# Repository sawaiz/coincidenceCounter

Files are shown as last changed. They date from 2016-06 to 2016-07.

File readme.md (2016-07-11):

# Coincidence Counter
The coincidence counter was developed as a means to collect data from cosmic ray detectors in a more cost efficient and straightforward way. The counter must collect, amplify, digitize, and record the coincidence of the analog signals from the detectors. The module attaches to the top of a Raspberry Pi and data is collected from the GPIO pins.

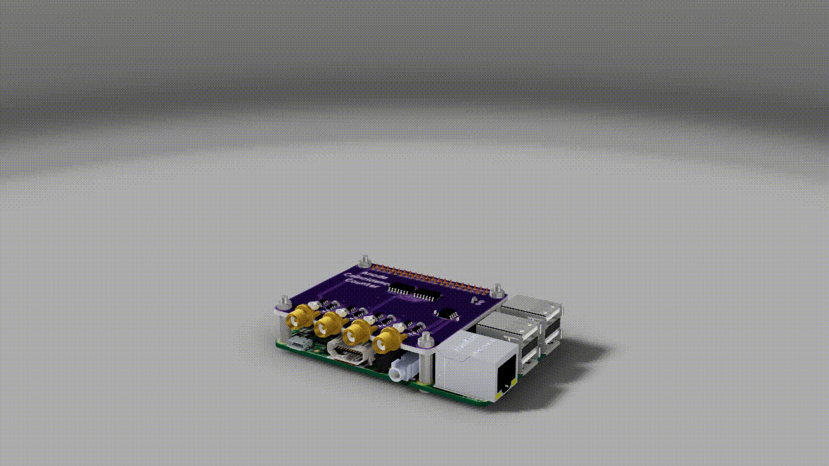
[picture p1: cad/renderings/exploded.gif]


## Electronics
The incoming signal (51 ohm termination) is first amplified by a factor of 10, with a [LT1809CS6](http://cds.linear.com/docs/en/datasheet/180910fa.pdf), a high bandwidth (320Mhz) operational amplifier in a non inverting configuration. This signal is fed into a ultrafast comparator [LT1719CS](http://cds.linear.com/docs/en/datasheet/1719fa.pdf) that has its threshold set through a potentiometer. Nanosecond level (10ns-100ns) signals are able to be digitized and sent out for analysis. The output is then put thorough the six possible *ANDs* of four signals which leads to interrupt pins on the Raspberry Pi.

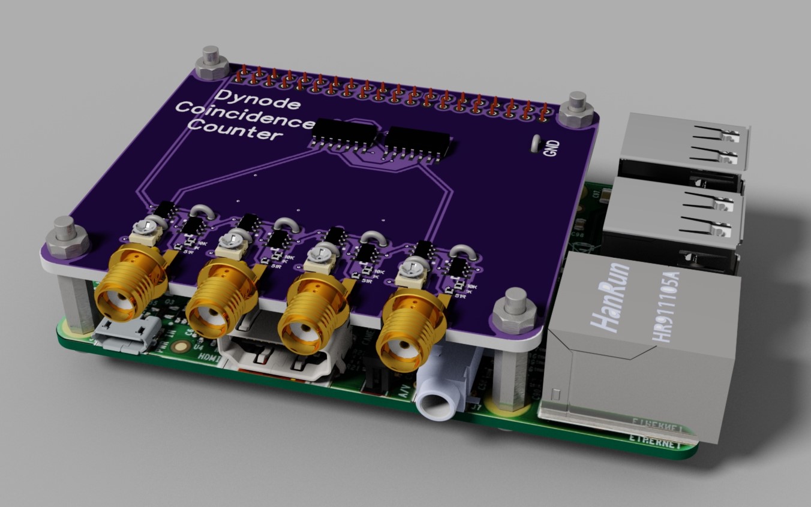
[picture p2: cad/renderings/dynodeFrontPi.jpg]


## Physical
The board is made with the [Pi HAT](https://github.com/raspberrypi/hats) specification, and leaves sufficient room for SMA cables to be attached. It does not contain a self configuration EEPROM. Its outputs are directly connected to the following pins.

| Output | GPIO | Inputs |
| --- | ----:| --- |
| 1 | 22 | CH1 & CH2 |
| 2 | 27 | CH3 & CH1 |
| 3 | 17 | CH1 & CH4 |
| 4 |  5 | CH4 & CH3 |
| 5 |  6 | CH2 & CH3 |
| 6 | 26 | CH2 & CH4 |

The board also has many test points, allowing checking of the signal, and setting of the potentiometers is a easier manner.

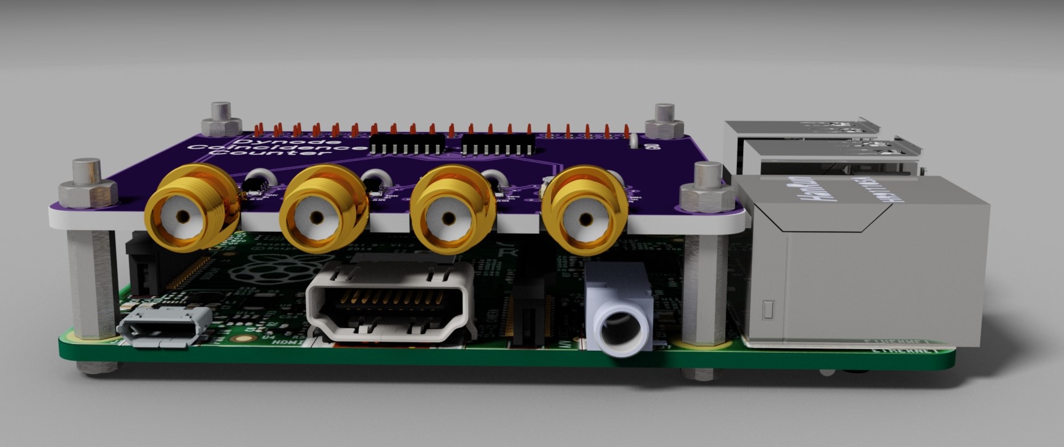
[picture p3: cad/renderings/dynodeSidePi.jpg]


## Usage
The repository [coincidenceControl](nope, deosnt exist yet) has instructions for installing and gathering data from this hardware.

[exploded]: cad/renderings/exploded.gif "Exploded animation of PCB"
[dynodeSidePi]: cad/renderings/dynodeSidePi.jpg "Side view showing clearance from other connectors"
[dynodeFrontPi]: cad/renderings/dynodeFrontPi.jpg "Board showing potentiometers and test points."

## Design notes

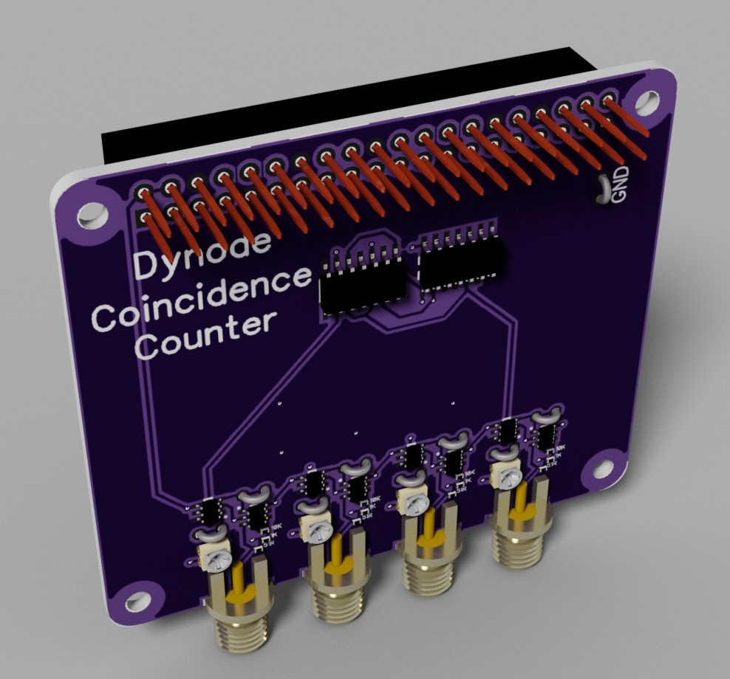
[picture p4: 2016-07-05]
cad/renderings/dinode isometric.jpg

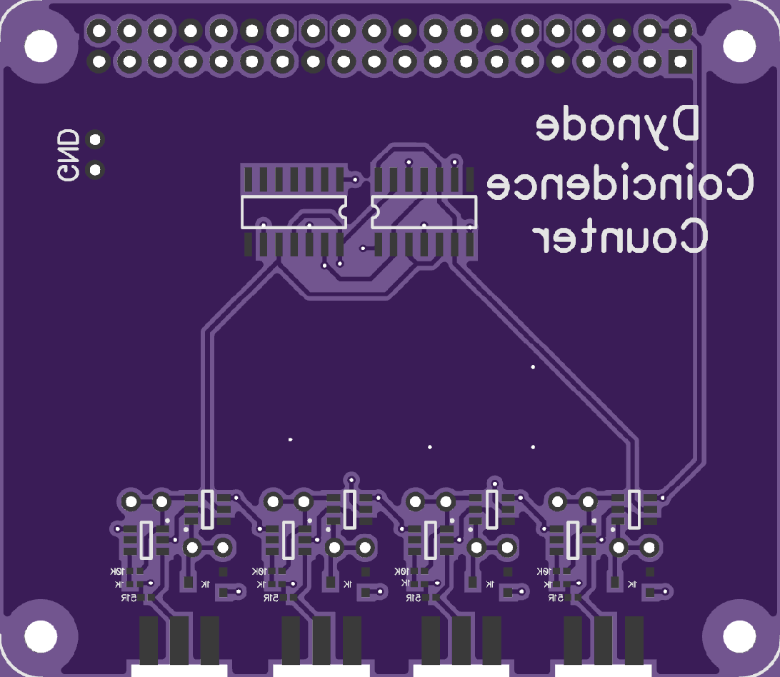
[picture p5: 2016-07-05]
cad/decals/top.png

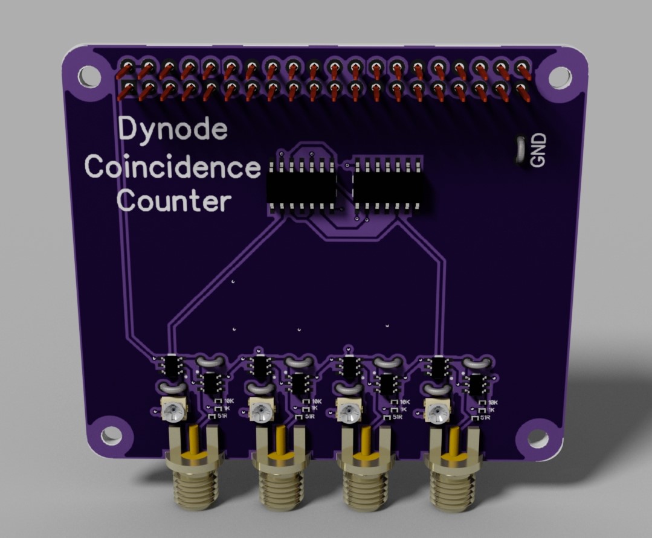
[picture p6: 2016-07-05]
cad/renderings/dinode front.jpg

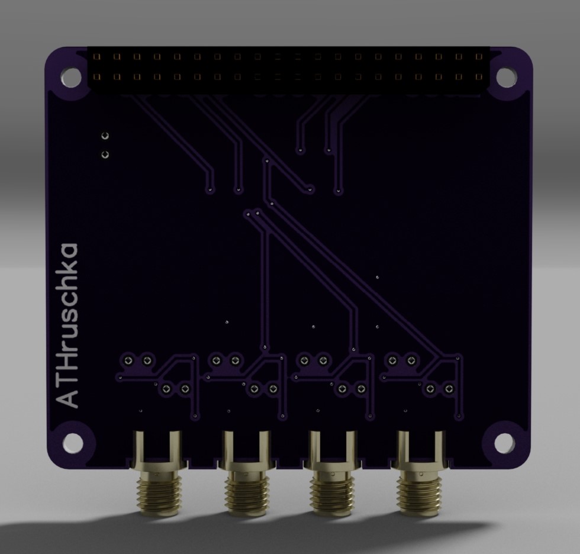
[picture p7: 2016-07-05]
cad/renderings/dinode back.jpg

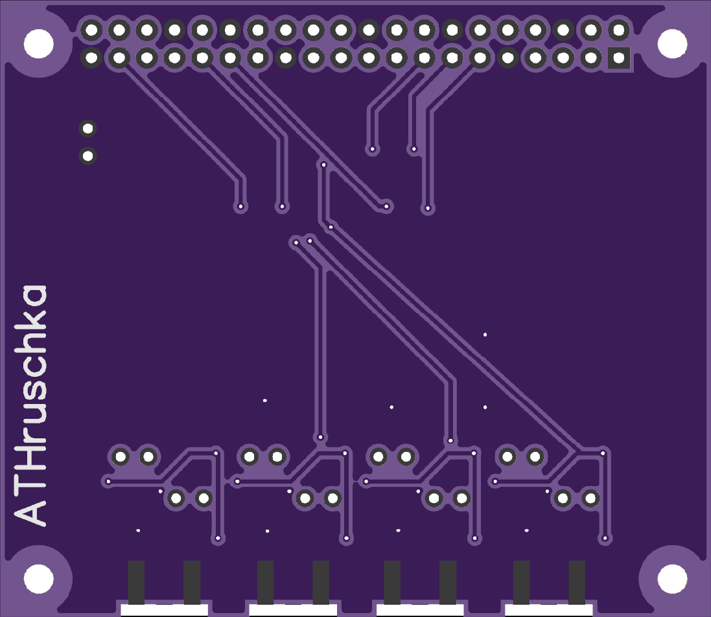
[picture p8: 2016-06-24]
cad/decals/bot.png

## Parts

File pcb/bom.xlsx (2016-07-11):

Ref-Des | Function | Description | P/N | Digikey P/N | QTY | Unit Price | Price Point | Extended Price | URL
R9 | res | RES SMD 1K OHM 5% 1/16W 0402 | CRG0402J1K0 | A106129CT-ND | 4 | $0.0037 | 100 | $0.01 | http://www.digikey.com/product-detail/en/te-connectivity-amp-connectors/CRG0402J1K0/A106129CT-ND/3477786
J1 | Analog Input | CONN SMA JACK 50 OHM EDGE MNT | CONSMA003.062 | CONSMA003.062 | 4 | $3.3700 | 1 | $13.48 | http://www.digikey.com/scripts/DkSearch/dksus.dll?Detail&itemSeq=200735391&uq=636027004667341576
U1 | NAND Gate | IC GATE NAND 4CH 2-INP 14-SO | 74HC00D,653 | 568-1379-1-ND | 2 | $0.4400 | 1 | $0.88 | http://www.digikey.com/scripts/DkSearch/dksus.dll?Detail&itemSeq=200735074&uq=636027004667321576
U2 | Analog to Digital Signal | IC COMP R-RINOUT SINGLE SOT23-6 | LT1719CS6#TRMPBF | LT1719CS6#TRMPBFCT-ND | 4 | $4.4800 | 1 | $17.92 | http://www.digikey.com/scripts/DkSearch/dksus.dll?Detail&itemSeq=200735921&uq=636027008193055389
U3 | Inverting Amplification of Signal | IC OPAMP GP 180MHZ RRO TSOT23-6 | LT1809CS6#TRMPBF | LT1809CS6#TRMPBFCT-ND | 4 | $4.4700 | 10 | $17.88 | http://www.digikey.com/product-detail/en/linear-technology/LT1809CS6-TRMPBF/LT1809CS6-TRMPBFCT-ND/891475
R8 | Potentiometer | TRIMMER 1K OHM 0.1W SMD | PVZ3A102C01R00 | 490-7004-1-ND | 4 | $0.1640 | 10 | $0.66 | http://www.digikey.com/scripts/DkSearch/dksus.dll?Detail&itemSeq=200735381&uq=636027011087621576
R10 | Res | RES SMD 51 OHM 0.5% 1/16W 0402 | RT0402DRE0751RL | 311-51UCT-ND | 4 | $0.0275 | 100 | $0.11 | http://www.digikey.com/product-detail/en/yageo/RT0402DRE0751RL/311-51UCT-ND/1037159
R | Res | RES SMD 10K OHM 0.1% 1/16W 0402 | RNCF0402BTE10K0 | RNCF0402BTE10K0CT-ND | 4 | $0.3100 | 10 | $1.24 | http://www.digikey.com/scripts/DkSearch/dksus.dll?Detail&itemSeq=200737314&uq=636027016498025803
 |  |  |  |  |  |  |  | $52.18

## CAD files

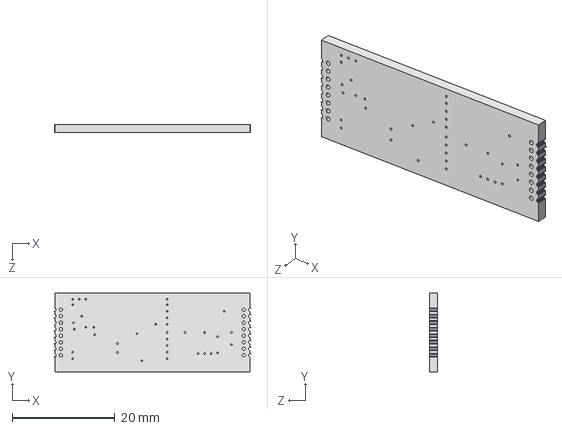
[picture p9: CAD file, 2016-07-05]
cad/board.step
38.2 x 15.4 x 1.60 mm

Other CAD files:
cad/electronics/2.54 breakaway/1x1.iam
cad/electronics/2.54 breakaway/1x3.iam
cad/electronics/2.54 breakaway/1x6.iam
cad/electronics/2.54 breakaway/1x8.iam
cad/electronics/2.54 breakaway/2x20.iam
cad/electronics/2.54 breakaway/Holder.ipt
cad/electronics/2.54 breakaway/Pin.ipt
cad/electronics/PVZ3A/PVZ3A.iam
cad/electronics/PVZ3A/User Library-PVZ3A_PVZ3A_base-1.ipt
cad/electronics/PVZ3A/User Library-PVZ3A_PVZ3A_con.ipt
cad/electronics/PVZ3A/User Library-PVZ3A_PVZ3A_res.ipt
cad/electronics/PVZ3A/User Library-PVZ3A_Pin1-1.ipt
cad/electronics/PVZ3A/User Library-PVZ3A_Pin1-1_1.ipt
cad/electronics/PVZ3A/User Library-PVZ3A_Pin1-1_2.ipt
cad/electronics/PVZ3A/User Library-PVZ3A_Pin2-1.ipt
cad/electronics/PVZ3A/User Library-PVZ3A_Pin2-2.ipt
cad/electronics/SMA Female Edge Mount CONSMA003-062.ipt
cad/electronics/SOT23-6.ipt
cad/electronics/femaleHeaders/960240-6202-AR Body.ipt
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

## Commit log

2015-10-07 Changed board layout, arduio sketch is in folder
2016-05-19 Revised logic schematic
2016-05-19 "Added bom"
    [bom.xlsx]
2016-05-20 Added cad in file structure.
    [bom.xlsx]
2016-05-20 Re-did layout structure once again
    [bom.xlsx]
2016-05-20 updated bom with pot
    [bom.xlsx]
2016-05-20 Exported pcb and decals for logic board
    [logic.step]
2016-05-20 Updated bom
    [bom.xlsx]
2016-05-23 Added output cad files
    [output.step]
2016-06-21 Fixed Everything
    [bom.xlsx]
2016-06-21 Finished board layout
2016-06-22 Used board mounted sma's
    [board.step, logic.step, output.step]
2016-06-24 Updated .step file
    [board.step]
2016-06-24 Fixed sma connectors
    [board.step]
2016-06-27 Updated board for 3V
2016-06-28 assembled board and renderings
    [1x1.iam, 1x3.iam, 1x6.iam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]
2016-07-05 updated assembly
    [960240-6202-AR Body.ipt, 960240-6202-AR Pin.ipt, femaleHeaders.iam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]
2016-07-08 updated rendering files
    [11mm M2.5 standoff.ipt, 960240-6202-AR Pin.ipt, M2.5 6mm screw.ipt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]
2016-07-11 honestly dont remember
    [bom.xlsx]
